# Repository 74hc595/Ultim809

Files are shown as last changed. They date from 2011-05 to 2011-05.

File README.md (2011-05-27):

Ultim809 Homebrew 8-Bit Computer
================================

Matt Sarnoff ([http://msarnoff.org/](http://msarnoff.org))

The Ultim809 is a homebrew 8-bit computer built around the Motorola 6809 processor. It's a full-featured home computer with color graphics, sound, and support for game controllers and PS/2 keyboards.

It won two blue ribbons (Editor's Choice awards) at Bay Area Maker Faire 2011!

Full feature list:

*  Motorola 68B09E processor at 2 MHz
*  512KB static RAM (bank-switched, 48KB available at once) expandable to 4MB
*  8KB EEPROM, self-programmable
*  TMS9918A graphics chip and composite video output (256x192 resolution, 15 colors, 32 sprites)
*  YM2149 sound chip (3 channels, square wave/noise, envelope generator)
*  Two ports for 9-pin Atari joysticks or Sega Genesis gamepads
*  Serial interface (16550 UART) with 6-pin FTDI connector
*  PS/2 keyboard support
*  I2C interface and DS1307 real-time clock with backup battery
*  SD card slot (not working yet...)
*  Expansion slot, supports 4 devices without additional decoding circuitry

I am making the schematics, design files, and source code available to anyone interested in learning about the project, or constructing their own. All material is made available under my (very simple) [msarnoff.org license.](http://www.msarnoff.org/LICENSE)

Schematics and PCB layout file are provided for use with the [open-source gEDA suite.](http://gpleda.org) Be aware that board revision 0 has errors: I have provided instructions on correcting them by cutting traces and adding wires.

Ultim809 currently has no working mass storage, so a PC with a Unix-like operating system (Linux, Mac OS X, etc.) and command-line skills are recommended for working with Ultim809. You'll also want a [5 volt FTDI USB-to-serial cable.](http://www.sparkfun.com/products/9718)

No microcontrollers or programmable logic chips are used, so an expensive programmer is not required. The 8K EEPROM can be programmed with a [simple Arduino circuit.](https://github.com/74hc595/ROMBurner)

The 68B09E is still available from Jameco and other electronics retailers, but you'll probably have to buy the TMS9918A and YM2149 from eBay.

Directory structure
-------------------
`circuit/` contains the schematic, bill of materials, and PCB layout files.

`code/` contains the assembly code for the ROM and application programs, as well as tools for writing your own programs.

`code/user/DEVELOPING.md` contains tips for developing Ultim809 applications. It assumes a familiarity with 6809 assembly language.

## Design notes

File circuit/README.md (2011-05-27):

Ultim809 Schematic and PCB Layout Files
=======================================

`ultim809.sch` is the up-to-date schematic in gEDA format.

`ultim809.pdf` is provided for those who do not have gEDA installed.

`bom.txt` is an up-to-date bill of materials, including sources and part numbers.

Snapshots of the schematic and PCB files for each board revision are included. Be aware that revision 0 has several design errors (steps to correct them are included in `bringup.pdf`) but it is included for completeness.

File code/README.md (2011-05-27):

Ultim809 Code
=============

This directory contains all assembly source code for the Ultim809 ROM and various application programs. Additional scripts to aid development are also included.

All code is written for the open-source ASxxxx cross assembler by Alan R. Baldwin, available online at [http://shop-pdp.kent.edu/ashtml/asxxxx.htm](http://shop-pdp.kent.edu/ashtml/asxxxx.htm). The SRecord suite is also required to create executable files. It's in many package repositories (including Ubuntu and MacPorts) and can also be downloaded from [http://srecord.sourceforge.net/](http://srecord.sourceforge.net/).

Directory structure
-------------------

`rom/` contains the ROM source, and various scripts to generate header files and checksums.

`user/` contains the source of various application programs, and a directory of common include files.

`ser09.py` is a script used to send programs to Ultim809 over a USB-to-serial cable. It can be used to download user programs, as well as update the ROM. See the file for usage details.

`gfx2inc.py` slices an image file into 8x8 or 16x16 tiles and converts them to hexadecimal `.fcb` directives, suitable for including in an assembly program.

`text2inc.py` converts a text file (any file, actually) to hexadecimal `.fcb` directives, suitable for including in an assembly program.

`ym2149.py` includes functions for converting frequencies in hertz to register values for the YM2149 sound chip, and vice versa.

`httpserial.py` is a script that acts as a serial-to-HTTP bridge, allowing Ultim809 to request the contents of URLs over the serial port.

`as6809.vim` is a syntax highlighting file for Vim.

Current features
----------------
Currently, Ultim809 has no mass storage and no interactive monitor. (The prototype did, and I'll be bringing these features over soon.) Programs must be loaded over the serial port using the following procedure:

1.  Make sure a USB-to-serial cable is connected to your PC.
2.  Make sure Ultim809 is on and running (HALT/RUN switch set to RUN).
3.  Press the INTERRUPT button. "Remote ready." should be displayed.
4.  On the PC, run `ser09.py run myprogram.s19`
5.  The status LED should blink yellow and the program should start when the transfer is complete. If not, run `ser09.py run`

The serial device can be changed with the `$SER09_PORT` environment variable. See the script for more details. The ser09 protocol is subject to change in future versions of the ROM.

Code has been written to do the following:

*  write to and read from the serial port
*  display numbers in hex and decimal
*  convert hex and decimal strings to 8- and 16-bit integers
*  generate random numbers with a simple linear feedback shift register
*  interface with the TMS9918A video chip and the YM2149 sound chip
*  read Atari joysticks and Sega 3-button gamepads
*  read the PS/2 keyboard using the 6522A, with a 16 byte scancode buffer
*  convert keyboard scancodes to ASCII characters
*  interface with I2C devices using the 6522
*  get data from the DS1307 real-time clock and set the time
*  download HTTP data from the httpserial.py script running on a PC

The following features of the board are not yet supported, but will be:

*  SPI using the 6522 shift register
*  reading and writing to SD cards
*  FAT16 filesystem operations
*  interactive monitor/command line

Emulation
---------
A somewhat-complete Ultim809 plugin for the MESS emulator is also available from my GitHub. It supports graphics, video, and gamepads, but the keyboard is not emulated.

Writing your own programs
-------------------------
See the `DEVELOPING.md` file in the `code/` directory to learn how to write your own assembly language programs. Note that future revisions of the ROM might require your programs to be reassembled.

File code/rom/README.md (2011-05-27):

Ultim809 ROM
============

A Makefile is included to build the ROM on a Unix-like machine with the ASxxxx assembler.

The following scripts are run by the Makefile:

`map2inc` takes the `rom.map` file as an input and generates a `rom0x.inc` header file, that defines the addresses of all global ROM subroutines. (those whose labels are suffixed with a double colon `::`) This file should be included by all user programs.

`gensums` computes the CRC32 and SHA1 hashes of the ROM binary and outputs the results in `checksum.h`. This file is used by the Ultim809 emulator for MESS.

Tests
-----
Simple test programs are provided in the `tests/` directory. They can be used to test basic system functionality before installing the full ROM.

Modifying the ROM
-----------------
Currently, all ROM routines are called by absolute address. If the ROM is modified, all user programs will have to be reassembled to reference the routines' new addresses, or they will crash. This is done for high performance, but may change in the future to improve portability.

ASlink apparently supports separate assembly, but in a very strange way that makes debugging difficult. The quick solution was to include all subroutine `.asm` files from `main.asm`. This means that a `make clean all` is required after modifying a file other than `main.asm`.

`remote.asm` contains the code to receive programs and ROM upgrades from `ser09`. Currently it only supports programming AT28C64B EEPROMs, 64 bytes at a time.

Uploading the ROM
-----------------
To bootstrap the system, you can use my ROMBurner Arduino sketch to burn the `rom.s19` file to an EEPROM chip with ser09:

`ser09.py load rom.s19`

Additionally, ser09 can be used to program the ROM directly on the board. In this case, power on the system, press the INTERRUPT button, turn the EEPROM PROTECT switch to OFF, and then run the command above. If all is OK, turn the EEPROM PROTECT switch back to ON and press the RESET button.

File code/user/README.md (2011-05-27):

Ultim809 User Programs
======================

These are some of the application programs I have written for Ultim809. Some are incomplete, but they demonstrate all the functionality of the machine.

For information on writing your own programs, see `DEVELOPING.md`.

The ser09 utility can be used to send programs to Ultim809. Connect a 5-volt FTDI USB-to-serial cable, power on the machine, and press the INTERRUPT button. Then, from a terminal on the PC, run

`ser09.py run myprogram.s19`

(`.s19` files are the Motorola equivalent of Intel HEX files, a text representation of the binary executable.) The status LED should blink yellow. If the program does not run after ser09 prints "All OK," you can issue the command

`ser09.py run`

Depending on your system, this might happen often. If that's the case, use this command instead:

`ser09.py load myprogram.s19 && ser09.py run`

Programs
--------

### asteroids
Nearly-complete Asteroids clone. The most complex Ultim809 program.

### date
Get and set the date/time from the DS1307 real time clock.

### kbdtest
Tests the PS/2 keyboard routines.

### life
Conway's Game of Life animation with color and generative music.

### padtest
Gamepad/joystick button test.

### plasma
Old-school rainbow plasma effect.

### vidtest
Basic test of the video chip.

### weather
Downloads and displays weather information using `httpserial.py` running on a host PC.

Include files
-------------
Supplemental routines, not included in the ROM, are provided in the `include/` directory.

### ds1307.asm
Routines to get and set the date and time from the DS1307.

### httpser.asm
Routines to communicate with `httpserial.py`.

### i2c.asm
Bit-banged I2C routines using the 6522A VIA.

### numio.asm
Routines to print numbers in decimal and convert strings to integers.

### random.asm
Simple LFSR-based pseudorandom number generator.

### readline.asm
Routine to read a line of input from the keyboard or serial port.

### ym2149.asm
Routines to interact with the YM2149 sound chip and read the game controllers.

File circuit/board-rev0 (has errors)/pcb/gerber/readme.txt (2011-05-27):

Layers:
u809.frontsilk.gbr    - silkscreen (top), includes board outline
u809.frontmask.gbr    - top solder mask
u809.front.gbr        - top copper
u809.back.gbr         - bottom copper
u809.backmask.gbr     - back solder mask

u809.plated-drill.cnc - Excellon drill file
u809.fab.gbr          - Fabrication drawing (informational only)

All files are positive polarity. Populated areas on solder mask files
indicate areas without solder mask.

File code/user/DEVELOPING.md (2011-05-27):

Developing Applications for Ultim809
====================================

What you'll need
----------------

*  A Unix-like system (Linux, Mac OS X, etc.) You're on your own if you use Windows.
*  A 6809 assembler. I use [ASxxxx](http://shop-pdp.kent.edu/ashtml/asxxxx.htm), and I have included Makefiles for it. It's full-featured, but uses somewhat nonstandard syntax. [asmx](http://xi6.com/projects/asmx/) uses traditional Motorola syntax, but I haven't tried it.
*  The SRecord package, installed through apt-get, MacPorts, or from the [website.](http://srecord.sourceforge.net)
*  I recommend using Vim with the `as6809.vim` syntax highlighting file (in the `code/` directory) and 8 spaces per tab.

6809 assembly language
----------------------
I won't go into the details of 6809 assembly language here. There are very few tutorials available, but the Motorola 6809 Programming Manual is available online [here](http://www.classiccmp.org/dunfield/r/6809prog.pdf) and is a good reference. I have also tried to comment my code as thoroughly as possible so that others might learn from it.

### The basics
There are two 8-bit accumulators, A and B. Together, they make up the 16-bit accumulator D. Supported operations include addition, subtraction, comparison, test, bitwise operations, shifts/rotates, and 8x8 unsigned multiply.

There are two 16-bit index registers, X and Y. They are typically used to hold pointers. All load, store and modify operations can use the addresses stored in X and Y, with optional displacement (by a constant or register value), autoincrement/decrement, and indirection.

There are not one, but _two_ stack pointers, S and U. Both act just like index registers, with the addition of "push" and "pull" instructions. S is the hardware stack pointer, used to store return addresses. You can do whatever you want with U, mostly it's used as a third index register.

The program counter, PC, is 16-bit, and can be used for program-counter-relative addressing when writing position-independent code.

DP is the direct page register, it holds the upper 8 bits of the effective address in direct addressing mode. **On the Ultim809 it should be kept set to 0, see below.**

CC is the condition code register. Condition flags are C (bit 0, carry), V (overflow), Z (zero), N (negative), I (IRQ interrupt inhibit), H (half-carry), F (FIRQ interrupt inhibit) and E (bit 7, entire machine state stacked on interrupt).

Most instructions operate on one register and one memory location (or immediate value). A couple instructions (transfer, exchange) operate on two registers, and some operate directly on memory. The 6809 has plenty of addressing modes, nearly all of which can be used with every instruction. See the programming manual for more information, there are too many to describe here, but they're awesome.

The address space
-----------------
The 6809, like other 8-bit processors, has a 16-bit address bus, and thus a 64K address space. The ROM lives at 0xE000-0xFFFF, and I/O devices are memory mapped in the range 0xC000-0xDFFF. The remaining 48K is RAM.

	0000 +-------------------------+
	     |                         | 0000-007F: system reserved RAM
	     |        User RAM         | 0080-00FF: availble zero-page RAM
	     |     (bank 0, fixed)     | 0100: user program start
	     |                         |
	4000 +-------------------------+
	     |                         |
	     |        User RAM         |
	     |     (bank 1, fixed)     |
	     |                         |
	8000 +-------------------------+
	     |                         |
	     |        User RAM         |
	     |    (selectable bank)    |
	     |                         |
	C000 +-------------------------+
	     |       I/O devices       | C001: bank select register
	     |      (see I/O map)      |
	E000 +-------------------------+
	     |           ROM           |
	     |       (8K EEPROM)       |
	     +-------------------------+

The RAM is divided into 16K banks. Banks 0 and 1 are always present in the lower 32K of the address space. The next 16K ($8000-$BFFF) is a user-selectable bank. The bank can be changed by writing to address $C001. (VIA output register A) A maximum of 256 banks (4 megabytes) are supported. The standard 512K system has 32 banks.

User programs are always loaded at address $0100. They are welcome to place their stack anywhere in user RAM, though I recommended the last address of bank 0 or 1 ($3FFF or $7FFF). **Note that the stack pointer should be initialized to one byte _past_ the last stack byte: i.e. $4000 or $8000.**

Direct page register
--------------------

While the 6502 allows direct addressing only from the zero page, the 6809 allows direct addressing from any of the 256 256-byte pages, controlled by the direct page register DP. For now, **do not mess with DP. Leave it set to 0.** The ROM routines expect DP to be 0, direct addressing is used to save space and cycles. If you're careful, you can mess with DP as long as you set it back to 0 before calling any ROM routines, but **the keyboard interrupt handler expects DP to be 0 as well.** You've been warned.

Interrupts and vectors
----------------------
The 6809 has three hardware interrupts (NMI, IRQ, and FIRQ) and three software interrupts (SWI, SWI2, and SWI3). All six interrupts transfer control to customizable vectors stored in the zero page. Interrupt behavior can be changed by storing interrupt handler addresses to `NMIVEC`, `IRQVEC`, `FIRQVEC`, `SWIVEC`, `SWI2VEC`, and `SWI3VEC`. 

### Hardware interrupts

NMI enters the monitor and enables remote program downloading. It is triggered by pressing the INTERRUPT button.

FIRQ is asserted by the VIA and is used for the keyboard handler. If you wish to use the keyboard and connect another interrupt source to FIRQ, your interrupt handler should call `KBD_HANDLER` to make sure the keyboard data bit is received.

IRQ is used for the TMS9918A VDP's vertical blanking interrupt. When enabled, it is asserted 60 times a second. The VDP's status register must be read to clear the interrupt.

### Software interrupts

The software interrupts are not currently used, but they will be in a future revision of the ROM.

SWI is intended to be used as a breakpoint instruction. It will trap into the monitor, keeping the program running.

SWI2 should be used as a "quit program" instruction. It will return control to the shell.

SWI3 has no planned use. Go nuts.

### Character input/output

The `OUTCH` and `INCH` vectors are used for character input and output routines. They act similar to standard input and output and may be configured to use the screen/keyboard or the serial port.

`OUTCH` is used by all the string/numeric output functions in the ROM.

Calling `UART_IO` will set up `OUTCH` and `INCH` to use the serial port.

The subroutine pointed to by `OUTCH` should take the character to be output in the B register and destroy no other registers.

The subroutine pointed to by `INCH` should return a character in the B register and destroy no other registers. It should block until a character has been received.

Program structure
-----------------

The typical control flow of a graphical application is fairly simple:

*  Set the stack pointer
*  Clear VRAM, turn the display off, and send pattern/color data to the VDP
*  Initialize program variables and data structures
*  Enable the keyboard and vblank interrupts
*  Turn the display on
*  Begin the logic update loop

The logic loop should be used for updating game/program logic. A `sync` instruction at the end of the loop (just before the jump back to the beginning) ensures it is called at a rate of 60 Hz.

The vblank interrupt handler should be used for all writes to video RAM, since there is no need to wait for an access window.

### Multiple assembler files

Since I haven't quite figured out separate assembly/linking with AS6809, the easiest way to assemble multiple files is to `.include` them at the end of the main `.asm` file. If one of the included files is modified, you'll have to rebuild with `make clean all`.

### Text-based programs

If you're making a "command-line" program that uses the screen in 40x24 text mode and the keyboard, you can set everything up with a call to `TEXT_CONSOLE` at the start of the program. All character I/O can then be done with `OUTCH` and `INCH`, and there is no need to directly manipulate video memory. A vblank handler is not installed.

### Program layout

See `stub.asm` and `Makefile_stub` for a new program template.

I/O devices
-----------

The I/O devices are accessed through memory addresses in the range $C000-$DFFF. Here is the full I/O device map:

	$C000-$C00F - 6522A Versatile Interface Adapter
	$C001       - bank select register (VIA port A output register)
	$C400-$C407 - 16550 UART (serial port)
	$C404       - controls status LED color (UART modem control register)
	$C800       - SPI input shift register
	$CC00-$CC01 - TMS9918A Video Display Processor
	$CC02-$CC03 - YM2149 Programmable Sound Generator
	$CC04       - read to select lower 16K of VRAM
	$CC06       - read to clear the controller SELECT lines
	$CC0C       - read to select upper 16K of VRAM
	$CC0E       - read to set the controller SELECT lines
	$D000-$D3FF - external device #1
	$D400-$D7FF - external device #2
	$D800-$DBFF - external device #3
	$DC00-$DFFF - external device #4
	
### 6522A VIA

[Datasheet](http://www.westerndesigncenter.com/wdc/documentation/w65c22.pdf)

The VIA is used mainly by the ROM routines, in most cases you don't need to touch it directly. Port A controls the upper 8 address lines, so writing to the port A output register (address $C001) changes the selected memory bank.

You should not change the Data Direction Registers. Port A should be set to all outputs and Port B should be set to all inputs.

### 16550 UART

[Datasheet](http://www.national.com/ds/PC/PC16550D.pdf)

The UART is initialized on powerup to operate at 38400 baud, 8 data bits, no parity, 1 stop bit. The `UART_INIT` subroutine can be used to reinitialize the UART with a different baud rate. You should pass the appropriate `B*` baud rate constant in the X register.

Calling `UART_IO` sets up the character I/O routines `OUTCH` and `INCH` to use the serial port.

The status LED is controlled by the two general-purpose outputs. `UART_SETLED` is a convenience method for changing the status LED color.

The FIFO, DMA, and interrupt functions are not used. The interrupt line is not connected.

### TMS9918A VDP

[Datasheet](http://www.cs.columbia.edu/~sedwards/papers/TMS9918.pdf)

The VDP has two addresses: the register write address, and the VRAM write address.

`tms9918.asm` in the `rom/` directory contains plenty of subroutines for interacting with the VDP and VRAM. Calling `VDP_CLEAR` at the start of your program is always a good idea to prevent graphics corruption.

`VDP_SET_REGS` sets all 8 control registers from an 8-byte block of memory pointed to by X.

`VDP_LOADPATS` makes it easy to copy 8-byte chunks of data (color table entries, pattern table entries) to VRAM.

`VDP_INITTEXT` automatically places the VDP in 40x24 text mode and copies the text character set to VRAM.

If possible, don't write to VRAM unless the display is off, or you're in the vblank handler. Read the datasheet: when the display is active, the VDP can require up to 8 microseconds before it's ready to write a byte to memory.

It's possible to transfer about 1K of data in the vertical blanking interval (which is 4300 microseconds long). It's enough for an entire name table update if you unroll your loop a whole lot.

The Ultim809 actually has 32K of VRAM, though the VDP can only access 16K at once. Doing an `lda` from `VBANK_LOWER` or `VBANK_UPPER` selects a VRAM bank. Its effectiveness as a double buffer is limited, since you can't write into one bank and have another displayed onscreen.

### YM2149 PSG

[Datasheet](http://www.ym2149.com/ym2149.pdf)

The YM2149 (also known as the AY-3-8910) runs off the 2MHz system clock. It has three channels, each of which can play a square wave, noise, or both. Each channel can either use a 4-bit volume value, or the waveform from the envelope generator.

Helpful subroutines, along with formulas to convert frequencies in Hz to register values, are in the `include/ym2149.asm` file.

The YM2149 is also used to read the controller ports. The two I/O ports should always be configured as inputs.

6809 assembler tips/idioms
--------------------------

This section won't serve as a full 6809 assembler tutorial, it's meant to be a collection of knowledge snippets I accumulated over the course of the project.

### Some index registers are faster than others
`ldy`/`sty` and `lds`/`sts` are one cycle _slower_ than `ldx`/`stx` and `ldu`/`stu`. It's recommended to use U as an index register before Y. `cmpx` is one cycle faster than all the other 16-bit register compares.

### 16-bit shifts and negation

Shift D left one bit:

	lslb
	rola
	
Shift D right one bit, unsigned:

	lsra
	rorb

Shift D right one bit, maintaining sign:

	asra
	rorb
	
Negate D:

	coma
	comb
	addd #1

### Reserve stack space during subroutines
If you run out of registers in a subroutine and need temporary space during a subroutine, use `leas` with a negative constant offset:

	leas -4,s	;reserve 4 bytes of stack space
	;do stuff
	leas 4,s	;restore stack space
	rts
		
### Know your flags

`inc` and `dec` affect the Negative, Zero, and Overflow flags. You can use a branch instruction directly after them.

All `ld` instructions set the Zero and Negative flags. You can use a branch instruction directly after them.

`leax` and `leay` set the Zero flag if the result is zero, `leas` and `leau` do not affect the Zero flag.

`clr` always sets the Carry flag. Use `ld #0` to zero a register without affecting the Carry flag.

### Quick 3-way logic tests
Branch instructions preserve the condition codes, so, for example, the following snippet can test if a number is zero, negative, or positive:

	ldb #somenumber
	beq number_is_zero
	bmi number_is_negative
	;number is positive
	
### Use `lea` instead of `tfr` with index registers
`leax ,y` is two cycles faster than `tfr y,x`.

### Use `lea` for 16-bit increments/decrements
`leax -1,x` will decrement X. `leax` and `leay` also set the Zero flag, so if you need a 16-bit loop counter, use X and Y instead of D.

### Tail calls
If the last instruction of a subroutine is a call to another subroutine, use `bra` or `jmp` instead of `bsr`/`jsr`. Also consider grouping subroutines together so one can "fall through" to another.

### Return from subroutine and restore registers with one instruction
`rts` is equivalent to `puls pc`. PC is always the last register pulled in a sequence, so if you had to push register values on the stack at the start of a subroutine, they can be restored along with the program counter. So instead of

	pshs d,x,y
	;do stuff here
	puls d,x,y
	rts

just do

	pshs d,x,y
	;do stuff here
	puls d,x,y,pc

This saves one byte and three cycles.

### For loops

If you have a free accumulator register, use it as the loop counter:

		lda  #5
	loop:
		;do stuff
		deca
		bne  loop
		
This works for up to 256 iterations: if A is 0, the `deca` will cause a wraparound and the loop will execute 256 times.

If you need both A and B during the loop, put the loop counter on the stack:

		lda  #5
		pshs a
	loop:
		;do stuff
		dec  ,s
		bne  loop
	done:
		leas 1,s
		
If you need a 16-bit loop counter, use X or Y, since `leax` and `leay` affect the Zero flag.

### Zero-terminated string/list processing
If you need to iterate through a list of characters/16-bit integers and stop when a zero is found, use autoincrementing address mode. For example, a routine to copy a null-terminated string pointed to by X to memory pointed to by Y:

	loop:
		ldb  ,x+
		beq  done
		stb  ,y+
		bra  loop

### Use constant offset indexing for data structures
Let's say X points to an array of 4-byte ordered pairs: a 2-byte x coordinate and a 2-byte y coordinate. Use `.equ` statements to give field names to structure offsets:

	xcoord		.equ 0
	ycoord		.equ 2
	POINT_SIZE	.equ 4
	
Now let's say you had a point in U and wanted to add its x and y coordinates to all points in the array pointed to by X. You could do something like this:

	loop:
		ldd  xcoord,x
		addd xcoord,u
		std  xcoord,x
		ldd  ycoord,x
		addd ycoord,u
		std  ycoord,x
		leax POINT_SIZE,x
		cmpx #POINTS_END
		bne  loop
		
### Table lookups
Indexed addressing with register offset is great for performing table lookups. For example, to get the byte in a table specified by the value in A:

	ldu  #TABLE
	ldb  a,u
	
A can be multiplied by 2 to perform a lookup in a table of 2-byte values:
	
	ldu  #TABLE
	lsla
	ldd  a,u
	
Note that register offsets are signed, so the first example only works with tables of 128 entries or less, and the second only works with tables of 64 entries or less.

There are a couple ways to perform a lookup in a table greater than 128 bytes and less than 256 bytes. One is to put the table pointer in X, the table offset in B, and use `abx`, which performs an unsigned addition:

	ldx  #TABLE
	abx
	ldb  b,x
	
The other is to shift B one bit left into A and use a 16-bit offset:

	ldu  #TABLE
	clra
	lslb
	rola
	ldb  d,u
	
However, this method is more expensive.

If your table is exactly 256 bytes, you can use an 8-bit register offset if you arrange your table in a clever way to take advantage of two's complement arithmetic. The first byte in the table will correspond to an offset of 128 (%10000000 or -128 in two's complement) The 129th byte will correspond to an offset of 0, so you should set your label to point to this byte in the table instead of the first. An example, using the identity table:

		.fcb 128,129,130,131
		;...
		;.fcb 252,253,254,255
	TABLE:
		.fcb 0,1,2,3
		;...
		.fcb 124,125,126,127
		
### Swap the bytes in a 16-bit number

	ldd  NUMBER
	exg  a,b
	std  NUMBER

Even better, if the source of the 16-bit numbers is a table, store them byte-swapped if possible!

### Set a YM2149 register with one instruction
When setting a register in the YM2149, first you write the register number to `PSG_LATCH_ADDR`, then the register value to `PSG_WRITE_ADDR`. However, since these addresses are right next to each other, both can be set with a 16-bit write:

	lda  #REGISTER_NUMBER
	ldb  #REGISTER_VALUE
	std  PSG
	
Or, combine both values with bitwise operations:

	ldd  #(REGISTER_NUMBER<<8)|REGISTER_VALUE
	std  PSG
	
### Set the VDP VRAM address
The TMS9918A has a strange memory addressing scheme: to write to or read from VRAM, the address must first be set, and it autoincrements with each read/write. When setting the VRAM address, two bytes must be written to the VDP register: the 14-bit VRAM address, with the secondmost-significant-bit set to 1, little-endian. The VDP can only receive a byte every 2 microseconds (4 cycles), so a 16-bit store instruction can't be used. Instead, write both bytes separately:

	ldd  #NEW_VRAM_ADDRESS
	ora  #0x40
	stb  VDP_REG
	sta  VDP_REG
	
The `VRAM` define is included to make things easier to understand:

	ldd	 #VRAM|NEW_VRAM_ADDRESS
	stb  VDP_REG
	sta  VDP_REG
	
### Sometimes it's better to not restore register values
Let's say you're writing a subroutine to process a chunk of data, like a zero-terminated string. You have a subroutine that takes a pointer to a zero-terminated string in X:

	SUBROUTINE:
		pshs x
	loop:
		ldb  ,x+
		beq  done
		;do stuff
		bra  loop
	done:
		puls x,pc
		
X is advanced inside the subroutine, but restored when it returns. Now what happens if you have to call this subroutine multiple times in a row?

	ldx  #string1
	jsr  SUBROUTINE
	ldx  #string2
	jsr  SUBROUTINE
	ldx  #string3
	jsr  SUBROUTINE
	;...
	string1: .asciz "This is string one"
	string2: .asciz "This is string two"
	string3: .asciz "This is string three"
	
If we modify `SUBROUTINE` to **not** restore X, it will point to the start of the next string on return, so we don't have to re-set X, and can just do this:

	ldx  #string1
	jsr  SUBROUTINE
	jsr  SUBROUTINE
	jsr  SUBROUTINE
	
If you're calling the same subroutine a bunch of times, it can be _faster_ to store the subroutine address in an index register:

	ldx  #string1
	ldu  #SUBROUTINE
	jsr  ,u
	jsr  ,u
	jsr  ,u

### Disable and enable interrupts
The 6809 doesn't have explicit enable/disable interrupt instructions. Instead, use the `orcc` and `andcc` instructions to directly modify the bits in the CC register:

	orcc  #0b01010000 ;disable interrupts (set bits F and I)
	andcc #0b10101111 ;enable interrupts (clear bits F and I)

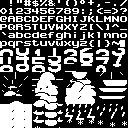
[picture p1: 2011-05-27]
code/user/weather/graphics.png

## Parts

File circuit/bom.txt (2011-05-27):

Refdes		Part			Value/part #	Qty	
B1		BATTERY_HOLDER		Jameco 355434	1	
C1,C3,C5,C6	POL_CAPACITOR		10uF		4	
C7		POL_CAPACITOR		1uF		1	
C8		CAPACITOR		27pF		1	
C9		CAPACITOR		47pF		1	
C10,C11,C14	CAPACITOR		33pF		3	
C12		POL_CAPACITOR		22uF		1	
C13,C16-C42	CAPACITOR		0.1uF		30	
C15		POL_CAPACITOR		220uF		1	
D1		1N4001					1	
D2,D3,D4	LED			GREEN, T1	3	
D5		LED			TRICOLOR, T1	1	
D6,D7		1N4148					2	
J1		PWRJACK			Jameco 101186	1	
J2		CONNECTOR_6				1	
J3		minidin-6		Jameco 119475	1	
J4		CONNECTOR_4				1	
J5		RCA, WHITE		Jameco 220581	1	
J6		RCA, YELLOW		Jameco 220564	1	
J7		CONNECTOR_11				1	
J8		SD_SOCKET				1	
J10,J9		DB9			Jameco 104943	2	
J11		HEADER34				1	
J12		HEADER40				1	
L1		BEAD					1	
Q1		2N3904 (center base)			1	
R1		RESISTOR		330		1	
R3-R8		RESISTOR		1k		6	
R9		RESISTOR		4.7k		1	
R10		RESISTOR		1M		1	
R11,R2		RESISTOR		1.5k		2	
R12,R14,R17	RESISTOR		1.8k		3	
R13,R15,R18	RESISTOR		3.3k		3	
R16		RESISTOR		10k		1	
R19		RESISTOR		470		1	
R20,R21		RESISTOR		75		2	
RN1,RN3		RESISTORPACK_6		10k		2	
RN2		RESISTORPACK_6		1k		1	
S1		SPDT ON-ON		Jameco 71597	1	
S4,S5		SPDT ON-ON		Jameco 75969	2	
S2,S3		PUSHBUTTON_NO				2	
U1		7805					1	
U2		LD1117V33				1	
U3		74HC73					1	
U4		MC68B09E				1	
U5		74HC00					1	
U6		74HC14					1	
U8		628512					1	
U9		28C64/AT28C64B				1	
U10		74HC138					1	
U11		6522A/W65C22S				1	
U12		74HC157					1	
U13		74HC08					1	
U14		74HC595					1	
U15		DS1307					1	
U16		16C550					1	
U17,U7		74HC139					2	
U18		74HC02					1	
U19		74HC74					1	
U20		YM2149			eBay		1	
U21		TMS9918A		eBay		1	
U22		74HC04					1	
U23,U24,U25	74HC574					3	
U26		62256					1	
U27		74HC245					1	
U28,U29		74HC541					2	
X1		OSC			8MHz		1	
X2		CRYSTAL			1.8432MHz	1	
X3		CRYSTAL			10.738635MHz	1	
X4		CRYSTAL			32.768kHz	1	
                                                                
		8-PIN DIP SOCKET			1	
		14-PIN DIP SOCKET			10	
		16-PIN DIP SOCKET			3	
		20-PIN DIP SOCKET			6	
		28-PIN DIP SOCKET			2	
		32-PIN DIP SOCKET			1	
		40-PIN DIP SOCKET			5

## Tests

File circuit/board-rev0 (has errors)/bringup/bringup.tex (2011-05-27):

\documentclass[letterpaper,11pt]{article}
\usepackage{fullpage}
\usepackage{graphicx}
\usepackage{underscore}
\usepackage{siunitx}

\newcommand{\net}[1]{\textsf{#1}}
\newcommand{\Net}[1]{\ensuremath{\overline{\textsf{#1}}}}
\newcommand{\Wbar}{\ensuremath{\overline{\textsf{W}}}}
\newcommand{\Vcc}{\net{Vcc}}
\newcommand{\GND}{\net{GND}}
\newcommand{\Pin}[1]{\textbf{Pin #1}}
\newcommand{\pin}[1]{\textbf{pin #1}}
\newcommand{\pins}[1]{\textbf{pins #1}}
\newcommand{\npin}[2]{\pin{#1} (\net{#2})}
\newcommand{\Npin}[2]{\pin{#1} (\Net{#2})}
\newcommand{\rpin}[2]{\refdes{#1} \pin{#2}}
\newcommand{\rpins}[2]{\refdes{#1} \pins{#2}}
\newcommand{\rnpin}[3]{\refdes{#1} \pin{#2} (\net{#3})}
\newcommand{\rNpin}[3]{\refdes{#1} \pin{#2} (\Net{#3})}
\newcommand{\rnpins}[3]{\refdes{#1} \pins{#2} (\net{#3})}
\newcommand{\refdes}[1]{\textbf{#1}}
\newcommand{\kohm}[1]{\SI{#1}{\kilo\ohm}}
\newcommand{\Mohm}[1]{\SI{#1}{\mega\ohm}}
\newcommand{\pF}[1]{\SI{#1}{\pico\farad}}
\newcommand{\uF}[1]{\SI{#1}{\micro\farad}}
\newcommand{\V}[1]{\SI{#1}{\volt}}
\newcommand{\MHz}[1]{\SI{#1}{\mega\hertz}}
\title{Ultim809 Rev 0 Board Bringup Procedure}
\author{Matt Sarnoff}
\date{\today}

\begin{document}
\maketitle
\section{Board Errors}
\subsection{\refdes{U4} \net{TSC}}
\Pin{39} of \refdes{U4} (\net{TSC}) is incorrectly connected to \Vcc. It should be connected to \GND. Cut the trace on the top side of the board as follows:

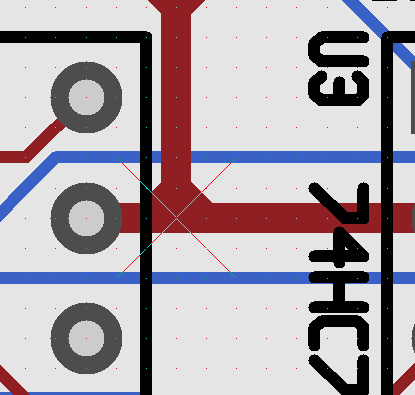
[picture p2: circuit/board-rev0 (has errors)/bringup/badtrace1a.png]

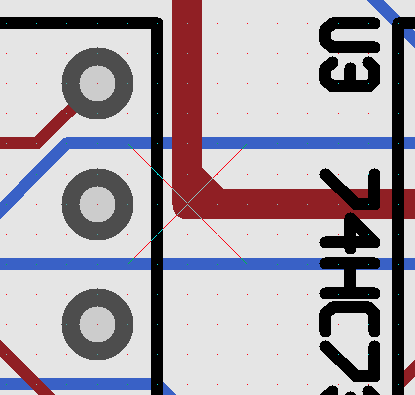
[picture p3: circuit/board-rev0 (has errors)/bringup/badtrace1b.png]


On the bottom of the board, solder a piece of enameled magnet wire or wire-wrap wire from \pin{39} to \pin{1}.

\subsection{\refdes{U16} \net{TX} and \net{RX} swapped}
\rnpin{U16}{10}{RX} is mistakenly connected to \rnpin{J2}{5}{RXD}, and \rnpin{U16}{11}{TX} is mistakenly connected to \rnpin{J2}{4}{TXD}. These two need to be swapped. Since it is difficult to fix this on the board, you will have to fashion an adapter on a piece of perfboard.

\subsection{\Net{CSW} and \Net{CSR} swapped}
\rNpin{U21}{14}{CSW} is mistakenly connected to \rpin{U17}{11} and \rNpin{U21}{15}{CSR} is mistakenly connected to \rpin{U17}{10}. The two should be swapped. Cut traces on the back of the board at \rpin{U17}{10-11}. Add a wire from \rpin{U17}{11} to \rpin{U21}{15} and a wire from \rpin{U17}{10} to \rpin{U21}{14}.

\subsection{VRAM bus incorrect}
Cut the traces on the back of the board at \rpin{U23}{12} and \rpin{U26}{26}. Add a wire from \rpin{U23}{19} to \rpin{U26}{4} and a wire from \rpin{U24}{19} to \rpin{U26}{26}.

\section{Assembly and testing}

\subsection{Sockets}
\begin{itemize}
\item Install all IC sockets.
\end{itemize}

\subsection{Power}
\begin{itemize}
\item Install \refdes{D2} (power LED), \refdes{R3} (\kohm{1}), \refdes{D1} (1N4001), \refdes{C2} and \refdes{C4} (\uF{0.1}), \refdes{C1} and \refdes{C3} (\uF{10} electrolytic, rated for \V{50}), \refdes{U1} (7805), \refdes{J1}, and \refdes{S1}.
\item Ensure \refdes{S1} is in the down (disconnected) position.
\item Connect \V{9} DC power to \refdes{J1}. The center pin is positive and the outer ring is ground.
\item Turn on \refdes{S1}. \refdes{D2} should light.
\item Measure \Vcc\ (for example, at \refdes{U14} \pin{16}) and ensure it is roughly \V{5}.
\end{itemize}

\subsection{Clock signals}
\begin{itemize}
\item Install \refdes{X1} (\MHz{8}), \refdes{U3} (74HC73), and decoupling capacitor \refdes{C16}.
\item Turn on power.
\item Using a frequency counter, measure the clock signals. \rpin{U3}{1} should read \MHz{8}. \rnpin{U4}{34}{E} and \rnpin{U4}{35}{Q} should read \MHz{2}.
\item Using a two-channel oscilloscope or logic analyzer, observe the \net{E} (\rpin{U4}{34}) and \net{Q} (\rpin{U4}{35}) waveforms.

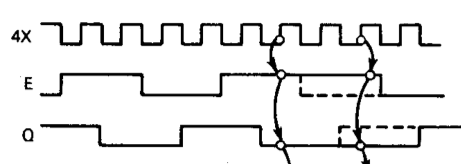
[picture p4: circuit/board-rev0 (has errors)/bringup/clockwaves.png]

\end{itemize}

\subsection{Processor integrity}
\begin{itemize}
\item Install \refdes{RN1} (\kohm{10}), \refdes{C6} (\uF{10}), \refdes{D3} and \refdes{D4}, \refdes{R4} and \refdes{R5} (\kohm{1}), \refdes{S5}, \refdes{S2}, and \refdes{S3}.
\item Flip \refdes{S5} up to HALT.
\item Turn on power.
\item Ensure \rNpin{U4}{40}{HALT} is \V{0}.
\item Ensure \Npin{U4}{37}{RESET}, \Npin{2}{NMI}, \Npin{3}{IRQ}, and \Npin{4}{FIRQ} are \V{5}.
\item Flip \refdes{S5} down to RUN and ensure \pin{40} is \V{5}.
\item Ensure \pin{37} is \V{0} when \refdes{S2} is depressed and \pin{2} is \V{0} when \refdes{S3} is depressed.
\item Turn off power, install \refdes{U4} (68B09E) and decoupling capacitor \refdes{C17}.
\item Flip \refdes{S5} up to HALT and turn on power.
\item Ensure \refdes{D3} and \refdes{D4} are both lit. This indicates the processor is in good condition.
\end{itemize}

\subsection{ROM, program execution, and address decoding}
\begin{itemize}
\item Burn \texttt{romtest1.s19} to an 8K$\times$8 EEPROM, using the Arduino ROMBurner and the \texttt{ser09} utility.
\item Install the EEPROM in \refdes{U9}, and install \refdes{U5} (74HC00), \refdes{U7} (74HC139), \refdes{RN3} (\kohm{10}), \refdes{S4}, and associated decoupling capacitors.
\item Flip \refdes{S4} to the left (EEPROM WRITE PROTECT ON) and ensure \rNpin{U9}{27}{WE} is connected to \rpin{RN3}{6}. (Resistance between \pin{27} and \Vcc\ is \kohm{10}.)
\item Flip \refdes{S4} to the right (EEPROM WRITE PROTECT OFF) and ensure \pin{27} is connected to \rNpin{U8}{29}{WR}.
\item Flip \refdes{S4} to the left and flip \refdes{S5} to HALT.
\item Turn on power. \refdes{D3} and \refdes{D4} should light.
\item Flip \refdes{S5} to RUN. \refdes{D3} and \refdes{D4} should turn off. The program should now be running. After about one second, \refdes{D3} should light (SYNC acknowledge), indicating the test program is finished. Pressing \refdes{S2} or \refdes{S3} will restart the program: the light will go out, and should come on about a second later.
\item Turn off power.
\item With a logic analyzer, attach probes to \rnpins{U4}{8-23}{A0-A15}, \rnpin{U4}{34}{E}, \rnpin{U4}{32}{R/\Wbar}, \rNpin{U5}{6}{RAMSEL}, \rNpin{U7}{4}{IOSEL}, \rNpin{U7}{5}{ROMSEL}, \rNpin{U7}{9}{RD}, and \rNpin{U7}{10}{WR}. The positive edge of \net{E} should be used as the clock signal.
\item Set \refdes{S5} to HALT, run the logic analyzer, and set \refdes{S5} to RUN. Repeat multiple times to verify the following truth table:

\begin{minipage}[t]{0.3\textwidth}
\begin{tabular}[t]{|c|c|c|c|}
\hline
\net{E} & \net{R/\Wbar} & \Net{RD} & \Net{WR} \\
\hline\hline
0 & x & 1 & 1 \\
1 & 1 & 0 & 1 \\
1 & 0 & 1 & 0 \\
\hline
\end{tabular}
\end{minipage}
\begin{minipage}[t]{0.5\textwidth}
\begin{tabular}[t]{|c|c|c|c|}
\hline
\net{A0-A15} & \Net{RAMSEL} & \Net{IOSEL} & \Net{ROMSEL} \\
\hline\hline
\$0xxx & 0 & 1 & 1 \\
\$1xxx & 0 & 1 & 1 \\
\$2xxx & 0 & 1 & 1 \\
\$3xxx & 0 & 1 & 1 \\
\$4xxx & 0 & 1 & 1 \\
\$5xxx & 0 & 1 & 1 \\
\$6xxx & 0 & 1 & 1 \\
\$7xxx & 0 & 1 & 1 \\
\$8xxx & 0 & 1 & 1 \\
\$9xxx & 0 & 1 & 1 \\
\$Axxx & 0 & 1 & 1 \\
\$Bxxx & 0 & 1 & 1 \\
\hline
\$Cxxx & 1 & 0 & 1 \\
\$Dxxx & 1 & 0 & 1 \\
\hline
\$Exxx & 1 & 1 & 0 \\
\$Fxxx & 1 & 1 & 0 \\
\hline
\end{tabular}
\end{minipage}

The test program attempts to read and write to successive addresses, so the address decoding may be observed.
\end{itemize}

\subsection{I/O decoding}
\begin{itemize}
\item Install \refdes{U6} (74HC14), \refdes{U10} (74HC138), and associated decoupling capacitors.
\item Attach logic analyzer probes to \rnpins{U4}{8-23}{A0-A15}, \rNpin{U10}{15}{VIASEL}, \rNpin{U10}{14}{UARTSEL}, \rNpin{U10}{13}{SRSEL}, \rNpin{U10}{12}{AVSEL}, \rNpin{U10}{11}{EXT1SEL}, \rNpin{U10}{10}{EXT2SEL}, \rNpin{U10}{9}{EXT3SEL}, \rNpin{U10}{7}{EXT4SEL}, and \rNpin{U5}{8}{EXTIOSEL}. The positive edge of \net{E} should be used as the clock signal.
\item Run \texttt{romtest1.s19} again and verify the following truth table: 

\begin{tabular}[t]{|c|c|c|c|c|c|c|c|c|c|}
\hline
\net{A0-A15} & \Net{VIA} & \Net{UART} & \Net{SR} & \Net{AV} & \Net{EXT1} & \Net{EXT2} & \Net{EXT3} & \Net{EXT4} & \Net{EXTIO} \\
\hline\hline
\$Bxxx & 1 & 1 & 1 & 1 & 1 & 1 & 1 & 1 & 1 \\
\$C000-\$C3FF & 0 & 1 & 1 & 1 & 1 & 1 & 1 & 1 & 1 \\
\$C400-\$C7FF & 1 & 0 & 1 & 1 & 1 & 1 & 1 & 1 & 1 \\
\$C800-\$CBFF & 1 & 1 & 0 & 1 & 1 & 1 & 1 & 1 & 1 \\
\$CC00-\$CFFF & 1 & 1 & 1 & 0 & 1 & 1 & 1 & 1 & 1 \\
\$D000-\$D3FF & 1 & 1 & 1 & 1 & 0 & 1 & 1 & 1 & 0 \\
\$D400-\$D7FF & 1 & 1 & 1 & 1 & 1 & 0 & 1 & 1 & 0 \\
\$D800-\$DBFF & 1 & 1 & 1 & 1 & 1 & 1 & 0 & 1 & 0 \\
\$DC00-\$DFFF & 1 & 1 & 1 & 1 & 1 & 1 & 1 & 0 & 0 \\
\$Exxx & 1 & 1 & 1 & 1 & 1 & 1 & 1 & 1 & 1 \\
\hline
\end{tabular}
\end{itemize}

\subsection{UART}
\begin{itemize}
\item Install \refdes{U16} (16C550), decoupling capacitor \refdes{C29}, \refdes{R10} (\Mohm{1}), \refdes{R11} (\kohm{1.5}), \refdes{C8} (\pF{27}), \refdes{C9} (\pF{47}), \refdes{X2} (\MHz{1.8432}), \refdes{J2}, \refdes{R1} (\SI{330}{\ohm}), \refdes{R2} (\kohm{1.5}), and \refdes{D5}. Orient \refdes{D5} so the shortest lead (the green anode) is on the left and is inserted into the square hole.
\item Burn \texttt{romtest2.s19} onto the EEPROM.
\item Connect a \V{5} FTDI USB-to-serial cable to \refdes{J2}, with the black wire on the right. Connect the other end to a PC. Start a terminal program listening at 38400 baud, 8 data bits, no parity, 1 stop bit.
\item Turn on the system and run the program.
\item The status LED \refdes{D5} should turn off and the system should print the following:
\begin{verbatim}
Hello World!
Type r, y, g, or o to change LED color
\end{verbatim}
Typing one of the four letters from the terminal changes the LED color (red, yellow, green, off) and prints a message. (``\texttt{Red.}'' or ``\texttt{Yellow.}'' or ``\texttt{Green.}'' or ``\texttt{Off.}'')
\item Additionally, use a frequency counter to check the UART's clock rate at \rpin{U16}{9}. It should be $16\times$ the baud rate: in this case, approximately \SI{614400}{\hertz}.
\end{itemize}

\subsection{RAM and bank switching}
\begin{itemize}
\item Install diode \refdes{D7} (1N4148).
\item Test \refdes{D7} using a multimeter in diode mode. Place the positive lead on \rNpin{U4}{4}{FIRQ} and place the negative lead on \rNpin{U11}{21}{IRQ}. (\refdes{U11} should not be installed yet.) The meter should read a small positive voltage. Reverse the leads and the meter should indicate an open circuit.
\item Install \refdes{U8} (512K SRAM), \refdes{U11} (W65C22S), \refdes{U12} (74HC157), \refdes{U13} (74HC08), and associated decoupling capacitors.
\item Burn \texttt{romtest3.s19} onto the EEPROM.
\item Connect the serial cable and start the terminal as in the previous step.
\item Run the program. It tries to determine the size of the RAM by cycling through the 16K pages and counting them until it detects wraparound. It should print
\begin{verbatim}
0512KB RAM available.
\end{verbatim}
on the console.
\end{itemize}

\subsection{Audio/video I/O decoding}
\begin{itemize}
\item Install \refdes{U17} (74HC139), \refdes{U18} (74HC02), \refdes{U19} (74HC74), and associated decoupling capacitors.
\item Burn \texttt{romtest4.s19} onto the EEPROM.
\item Attach logic analyzer probes to \rNpin{U17}{1}{AVSEL}, \rnpin{U17}{2-3}{A1-A2}, \rNpin{U17}{4}{VDPSEL}, \rNpin{U17}{5}{PSGSEL}, \rNpin{U17}{6}{FF1SEL}, \rNpin{U17}{7}{FF2SEL}, \rNpin{U17}{13}{RD}, \rNpin{U17}{14}{WR}, \rNpin{U17}{10}{CSR}, \rNpin{U17}{11}{CSW}, \rnpin{U18}{3}{A0}, \rnpin{U18}{1}{BC1}, \rnpin{U18}{4}{BDIR}, \rnpin{U18}{13}{FF1CP}, \rnpin{U18}{10}{FF2CP}, \rnpin{U19}{3}{A3}, \rnpin{U19}{5}{VBANK}, and \rnpin{U19}{9}{PADSELECT}. The positive edge of \net{E} should be used as the clock signal.
\item Run the program and verify the following truth tables:

\begin{tabular}{|c|c|c|c|c|c|c|c|c|c|}
\hline
\Net{AVSEL} & \net{A0-A2} & \Net{RD} & \Net{WR} & \Net{VDPSEL} & \Net{PSGSEL} & \Net{FF1SEL} & \Net{FF2SEL} & \Net{CSR} & \Net{CSW} \\
\hline
1 & \%xxx & x & x &   1 & 1 & 1 & 1 &   1 & 1 \\
0 & \%00x & 1 & 0 &   0 & 1 & 1 & 1 &   1 & 0 \\
0 & \%00x & 0 & 1 &   0 & 1 & 1 & 1 &   0 & 1 \\
0 & \%01x & x & x &   1 & 0 & 1 & 1 &   1 & 1 \\
0 & \%10x & x & x &   1 & 1 & 0 & 1 &   1 & 1 \\
0 & \%11x & x & x &   1 & 1 & 1 & 0 &   1 & 1 \\
\hline
\end{tabular}

\begin{tabular}{|c|c|c|c|c|c|c|}
\hline
\Net{AVSEL} & \Net{PSGSEL} & \net{A0-A2} & \Net{RD} & \Net{WR} & \net{BC1} & \net{BDIR} \\
\hline
1 & 1 & \%xxx & x & x & 0 & 0 \\
0 & 0 & \%010 & x & 0 & 1 & 1 \\
0 & 0 & \%010 & x & 1 & 1 & 0 \\
0 & 0 & \%011 & x & 0 & 0 & 1 \\
0 & 0 & \%011 & x & 1 & 0 & 0 \\
\hline
\end{tabular}

\begin{tabular}{|c|c|c|c|c|c|c|c|c|}
\hline
\Net{AVSEL} & \Net{FF1SEL} & \Net{FF2SEL} & \Net{RD} & \net{A3} & \net{FF1CP} & \net{FF2CP} & \net{VBANK} & \net{PADSELECT} \\
\hline
1 & 1 & 1 &   x & x &  0 & 0 &  no change & no change \\
0 & 0 & 1 &   1 & x &  0 & 0 &  no change & no change \\
0 & 0 & 1 &   0 & 0 &  1 & 0 &  0 & no change \\
0 & 0 & 1 &   0 & 1 &  1 & 0 &  1 & no change \\
0 & 1 & 0 &   0 & 0 &  0 & 1 &  no change & 0 \\
0 & 1 & 0 &   0 & 1 &  0 & 1 &  no change & 1 \\
\hline
\end{tabular}
\end{itemize}

\subsection{Audio/gamepads}
\begin{itemize}
\item Install \refdes{U20} (YM2149), \refdes{R6}, \refdes{R7}, and \refdes{R8} (\kohm{1}), \refdes{R9} (\kohm{4.7}), \refdes{C7} (\uF{1}), \refdes{J9}, and \refdes{J10}. Also install decoupling capacitors.
\end{itemize}

\subsection{Video}
\begin{itemize}
\item Install \refdes{U21} (TMS9918A), \refdes{U22} (74HC04), \refdes{U23}, \refdes{U24}, and \refdes{U25} (74HC574), \refdes{U26} (62256), \refdes{D6} (1N4148), \refdes{C10} and \refdes{C11} (\pF{33}), \refdes{X3} (\MHz{10.738635}), \refdes{R19} (\SI{470}{\ohm}), \refdes{R20} and \refdes{R21} (\SI{75}{\ohm}), \refdes{C12} (\uF{22}), \refdes{C13} (\uF{0.1}), \refdes{C15} (\uF{220}), \refdes{L1} (ferrite bead), \refdes{Q1} (2N3904), and \refdes{J6}. Also install decoupling capacitors.
\end{itemize}

\end{document}

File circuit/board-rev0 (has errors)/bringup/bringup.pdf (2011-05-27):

## Ultim809 Rev 0 Board Bringup Procedure

Matt Sarnoff

May 11, 2011

## 1 Board Errors

### 1.1 U4 TSC

Pin 39 of U4 (TSC) is incorrectly connected to Vcc. It should be connected to GND. Cut the trace on the top side of the board as follows:

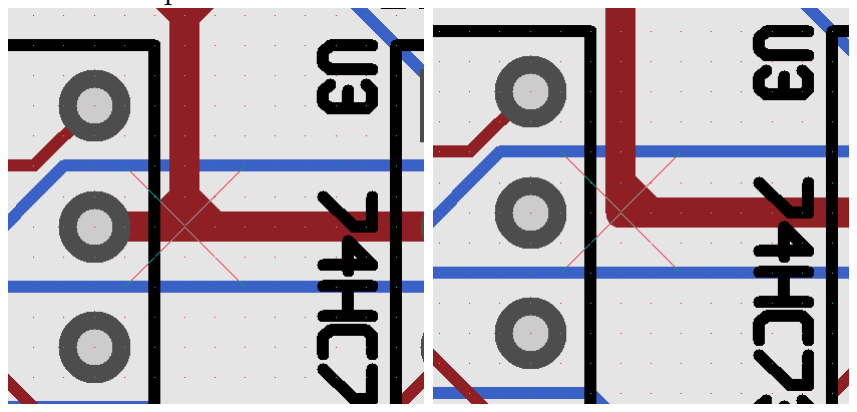
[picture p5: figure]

On the bottom of the board, solder a piece of enameled magnet wire or wire-wrap wire from pin 39 to pin 1.

### 1.2 U16 TX and RX swapped

U16 pin 10 (RX) is mistakenly connected to J2 pin 5 (RXD), and U16 pin 11 (TX) is mistakenly connected to J2 pin 4 (TXD). These two need to be swapped. Since it is difficult to fix this on the board, you will have to fashion an adapter on a piece of perfboard.

### 1.3 CSW and CSR swapped

U21 pin 14 (CSW) is mistakenly connected to U17 pin 11 and U21 pin 15 (CSR) is mistakenly connected to U17 pin 10. The two should be swapped. Cut traces on the back of the board at U17 pin 10-11. Add a wire from U17 pin 11 to U21 pin 15 and a wire from U17 pin 10 to U21 pin 14.

### 1.4 VRAM bus incorrect

Cut the traces on the back of the board at U23 pin 12 and U26 pin 26. Add a wire from U23 pin 19 to U26 pin 4 and a wire from U24 pin 19 to U26 pin 26.

1

## 2 Assembly and testing

### 2.1 Sockets

- Install all IC sockets.

### 2.2 Power

- Install D2 (power LED), R3 (1 kΩ), D1 (1N4001), C2 and C4 (0.1 µF), C1 and C3 (10 µF electrolytic, rated for 50 V), U1 (7805), J1, and S1.
- Ensure S1 is in the down (disconnected) position.
- Connect 9 V DC power to J1. The center pin is positive and the outer ring is ground.
- Turn on S1. D2 should light.
- Measure Vcc (for example, at U14 pin 16) and ensure it is roughly 5 V.

### 2.3 Clock signals

- Install X1 (8 MHz), U3 (74HC73), and decoupling capacitor C16.
- Turn on power.
- Using a frequency counter, measure the clock signals. U3 pin 1 should read 8 MHz. U4 pin 34 (E) and U4 pin 35 (Q) should read 2 MHz.
- Using a two-channel oscilloscope or logic analyzer, observe the E (U4 pin 34) and Q (U4 pin 35) waveforms.

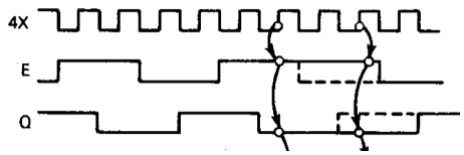
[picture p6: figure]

### 2.4 Processor integrity

- Install RN1 (10 kΩ), C6 (10 µF), D3 and D4, R4 and R5 (1 kΩ), S5, S2, and S3.
- Flip S5 up to HALT.
- Turn on power.
- Ensure U4 pin 40 (HALT) is 0 V.
- Ensure pin U4 (37)RESET, pin 2 (NMI), pin 3 (IRQ), and pin 4 (FIRQ) are 5 V.

2

- Flip S5 down to RUN and ensure pin 40 is 5 V.
- Ensure pin 37 is 0 V when S2 is depressed and pin 2 is 0 V when S3 is depressed.
- Turn off power, install U4 (68B09E) and decoupling capacitor C17.
- Flip S5 up to HALT and turn on power.
- Ensure D3 and D4 are both lit. This indicates the processor is in good condition.

### 2.5 ROM, program execution, and address decoding

- Burn romtest1.s19 to an 8K×8 EEPROM, using the Arduino ROMBurner and the ser09 utility.
- Install the EEPROM in U9, and install U5 (74HC00), U7 (74HC139), RN3 (10 kΩ), S4, and associated decoupling capacitors.
- Flip S4 to the left (EEPROM WRITE PROTECT ON) and ensure U9 pin 27 (WE) is connected to RN3 pin 6. (Resistance between pin 27 and Vcc is 10 kΩ.)
- Flip S4 to the right (EEPROM WRITE PROTECT OFF) and ensure pin 27 is connected to U8 pin 29 (WR).
- Flip S4 to the left and flip S5 to HALT.
- Turn on power. D3 and D4 should light.
- Flip S5 to RUN. D3 and D4 should turn off. The program should now be running. After about one second, D3 should light (SYNC acknowledge), indicating the test program is finished. Pressing S2 or S3 will restart the program: the light will go out, and should come on about a second later.
- Turn off power.
- With a logic analyzer, attach probes to U4 pins 8-23 (A0-A15), U4 pin 34 (E), U4 pin 32 (R/W), U5 pin 6 (RAMSEL), U7 pin 4 (IOSEL), U7 pin 5 (ROMSEL), U7 pin 9 (RD), and U7 pin 10 (WR). The positive edge of E should be used as the clock signal.
- Set S5 to HALT, run the logic analyzer, and set S5 to RUN. Repeat multiple times to verify the following truth table:

3

E | R/W | RD | WR
0 | x | 1 | 1
1 | 1 | 0 | 1
1 | 0 | 1 | 0
A0-A15 | RAMSEL | IOSEL | ROMSEL
$0xxx | 0 | 1 | 1
$1xxx | 0 | 1 | 1
$2xxx | 0 | 1 | 1
$3xxx | 0 | 1 | 1
$4xxx | 0 | 1 | 1
$5xxx | 0 | 1 | 1
$6xxx | 0 | 1 | 1
$7xxx | 0 | 1 | 1
$8xxx | 0 | 1 | 1
$9xxx | 0 | 1 | 1
$Axxx | 0 | 1 | 1
$Bxxx | 0 | 1 | 1
$Cxxx $Dxxx | 1 1 | 0 0 | 1 1
$Exxx $Fxxx | 1 1 | 1 1 | 0 0

The test program attempts to read and write to successive addresses, so the address decoding may be observed.

### 2.6 I/O decoding

- Install U6 (74HC14), U10 (74HC138), and associated decoupling capacitors.
- Attach logic analyzer probes to U4 pins 8-23 (A0-A15), U10 pin 15 (VIASEL), U10 pin 14 (UARTSEL), U10 pin 13 (SRSEL), U10 pin 12 (AVSEL), U10 pin 11 (EXT1SEL), U10 pin 10 (EXT2SEL), U10 pin 9 (EXT3SEL), U10 pin 7 (EXT4SEL), and U5 pin 8 (EXTIOSEL). The positive edge of E should be used as the clock signal.
- Run romtest1.s19 again and verify the following truth table:
A0-A15 | VIA | UART | SR | AV | EXT1 | EXT2 | EXT3 | EXT4 | EXTIO
$Bxxx $C000-$C3FF $C400-$C7FF $C800-$CBFF $CC00-$CFFF $D000-$D3FF $D400-$D7FF $D800-$DBFF $DC00-$DFFF $Exxx | 1 0 1 1 1 1 1 1 1 1 | 1 1 0 1 1 1 1 1 1 1 | 1 1 1 0 1 1 1 1 1 1 | 1 1 1 1 0 1 1 1 1 1 | 1 1 1 1 1 0 1 1 1 1 | 1 1 1 1 1 1 0 1 1 1 | 1 1 1 1 1 1 1 0 1 1 | 1 1 1 1 1 1 1 1 0 1 | 1 1 1 1 1 0 0 0 0 1

4

### 2.7 UART

- Install U16 (16C550), decoupling capacitor C29, R10 (1 MΩ), R11 (1.5 kΩ), C8 (27 pF), C9 (47 pF), X2 (1.8432 MHz), J2, R1 (330 Ω), R2 (1.5 kΩ), and D5. Orient D5 so the shortest lead (the green anode) is on the left and is inserted into the square hole.
- Burn romtest2.s19 onto the EEPROM.
- Connect a 5 V FTDI USB-to-serial cable to J2, with the black wire on the right. Connect the other end to a PC. Start a terminal program listening at 38400 baud, 8 data bits, no parity, 1 stop bit.
- Turn on the system and run the program.
- The status LED D5 should turn off and the system should print the following:

Hello World!
Type r, y, g, or o to change LED color

Typing one of the four letters from the terminal changes the LED color (red, yellow, green, off) and prints a message. (“Red.” or “Yellow.” or “Green.” or “Off.”)

- Additionally, use a frequency counter to check the UART’s clock rate at U16 pin 9. It should be 16× the baud rate: in this case, approximately 614 400 Hz.

### 2.8 RAM and bank switching

- Install diode D7 (1N4148).
- Test D7 using a multimeter in diode mode. Place the positive lead on U4 pin 4 (FIRQ) and place the negative lead on U11 pin 21 (IRQ). (U11 should not be installed yet.) The meter should read a small positive voltage. Reverse the leads and the meter should indicate an open circuit.
- Install U8 (512K SRAM), U11 (W65C22S), U12 (74HC157), U13 (74HC08), and associated decoupling capacitors.
- Burn romtest3.s19 onto the EEPROM.
- Connect the serial cable and start the terminal as in the previous step.
- Run the program. It tries to determine the size of the RAM by cycling through the 16K pages and counting them until it detects wraparound. It should print

0512KB RAM available.

on the console.

5

### 2.9 Audio/video I/O decoding

- Install U17 (74HC139), U18 (74HC02), U19 (74HC74), and associated decoupling capacitors.
- Burn romtest4.s19 onto the EEPROM.
- Attach logic analyzer probes to U17 pin 1 (AVSEL), U17 pin 2-3 (A1-A2), U17 pin 4 (VDPSEL), U17 pin 5 (PSGSEL), U17 pin 6 (FF1SEL), U17 pin 7 (FF2SEL), U17 pin 13 (RD), U17 pin 14 (WR), U17 pin 10 (CSR), U17 pin 11 (CSW), U18 pin 3 (A0), U18 pin 1 (BC1), U18 pin 4 (BDIR), U18 pin 13 (FF1CP), U18 pin 10 (FF2CP), U19 pin 3 (A3), U19 pin 5 (VBANK), and U19 pin 9 (PADSELECT). The positive edge of E should be used as the clock signal.
- Run the program and verify the following truth tables:
AVSEL | A0-A2 | RD | WR | VDPSEL | PSGSEL | FF1SEL | FF2SEL | CSR | CSW
1 0 0 0 0 0 | %xxx %00x %00x %01x %10x %11x | x 1 0 x x x | x 0 1 x x x | 1 0 0 1 1 1 | 1 1 1 0 1 1 | 1 1 1 1 0 1 | 1 1 1 1 1 0 | 1 1 0 1 1 1 | 1 0 1 1 1 1
AVSEL | PSGSEL | A0-A2 | RD | WR | BC1 | BDIR
1 0 0 0 0 | 1 0 0 0 0 | %xxx %010 %010 %011 %011 | x x x x x | x 0 1 0 1 | 0 1 1 0 0 | 0 1 0 1 0
AVSEL | FF1SEL | FF2SEL | RD | A3 | FF1CP | FF2CP | VBANK | PADSELECT
1 0 0 0 0 0 | 1 0 0 0 1 1 | 1 1 1 1 0 0 | x 1 0 0 0 0 | x x 0 1 0 1 | 0 0 1 1 0 0 | 0 0 0 0 1 1 | no change no change 0 1 no change no change | no change no change no change no change 0 1

### 2.10 Audio/gamepads

- Install U20 (YM2149), R6, R7, and R8 (1 kΩ), R9 (4.7 kΩ), C7 (1 µF), J9, and J10. Also install decoupling capacitors.

### 2.11 Video

- Install U21 (TMS9918A), U22 (74HC04), U23, U24, and U25 (74HC574), U26 (62256), D6 (1N4148), C10 and C11 (33 pF), X3 (10.738 635 MHz), R19 (470 Ω), R20 and R21 (75 Ω), C12 (22 µF), C13 (0.1 µF), C15 (220 µF), L1 (ferrite bead), Q1 (2N3904), and J6. Also install decoupling capacitors.

6

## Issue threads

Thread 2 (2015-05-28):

error in schematic

phiber1, 2015-05-28:
Hello Matt, I happened to notice an error in your schematic.  Specifically U17, the second decoder in the 74139 being used to do the chip-select read and chip-select write on the VDP... Your decoding of A and B to Y1 and Y2 is backwards.  If you consult the truth table, \A -> \Y2, and \B -> \Y1.  So you either need to reverse your schematic wiring of \WR and \RD at the inputs, or otherwise reverse \CSW and \CSR at the outputs.  Either or.  Otherwise the VDP obviously won't work at all.

Regards,
Mark

74hc595, 2018-09-21:
This is a known error and is documented here: https://github.com/74hc595/Ultim809/blob/master/circuit/board-rev0%20(has%20errors)/rev0-errors.txt

Sorry it has taken an eternity for me to respond! This project has been on the shelf for a while. I'd love to do a second revision of the Ultim809 and fix the errors one of these days.

phiber1, 2018-09-21:
So it is! I've never actually built your system, but I created my own 63C09
homebrew some years back which runs FLEX and CUBIX OSes.
I have a different sound chip in mine, but I did adapt your Asteroids game
to run on my system, adjusting for the sounds. I also corrected the "OUT OF
OBJECTS!" error for those of us that actually play well and go on for a
while.  :)
Well done.

-Mark

On Fri, Sep 21, 2018 at 12:12 PM, Matt Sarnoff <notifications@github.com>
wrote:

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

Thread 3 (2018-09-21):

name of the library book used for your design?

xedover, 2018-09-21:
You said you "found a microcomputer design book at the library that uses the 6809 in its examples." Can you tell us the name of the book?

cbmeeks, 2018-09-21:
+1

74hc595, 2018-09-21:
Oh boy. I can't remember the name, but it was already out of print when I checked it out. I recall it was the first edition of the book; later editions used the 68000. It wasn't a large book; maybe half an inch thick.

I think my only lead might be to find my old Santa Clara County Library card, log into their website, and  see if it's in my checkout history.

phiber1, 2018-09-21:
Now that I have your attention, there's a crucial error in your schematic
in the graphics logic section. I opened an issue about it a few years ago.

-Mark

On Fri, Sep 21, 2018, 11:56 AM Matt Sarnoff <notifications@github.com>
wrote:

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

74hc595, 2018-09-21:
@phiber1 Thank you for the reminder, I just replied to your issue.

74hc595, 2018-09-22:
*This is it!* _Microprocessor System Design Fundamentals_ by Kenneth J. Breeding: https://www.amazon.com/Microprocessor-System-Fundamentals-Kenneth-Breeding/dp/0135642795

Closed 2018-09-22.

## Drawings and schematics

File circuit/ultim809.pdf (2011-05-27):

## 40VDD

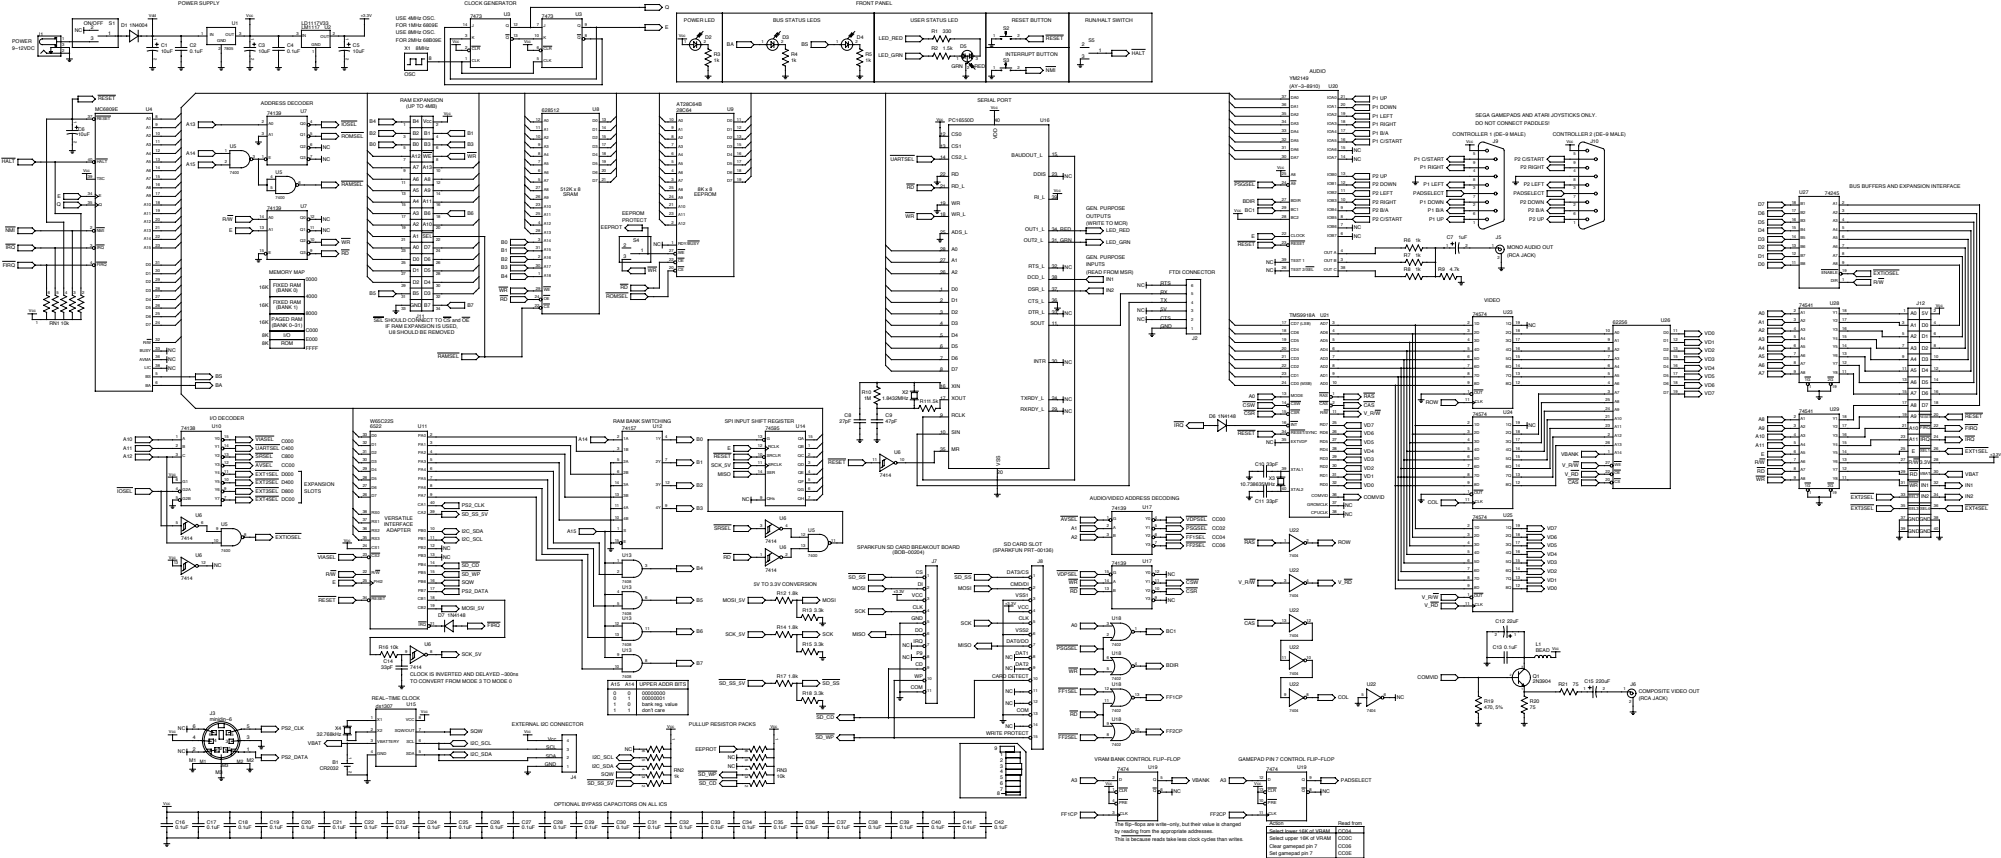
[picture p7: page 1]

SEGA GAMEPADS AND ATARI JOYSTICKS ONLY.
DO NOT CONNECT PADDLES!

BUS BUFFERS AND EXPANSION INTERFACE

SEL SHOULD CONNECT TO CS and OE
IF RAM EXPANSION IS USED,
U8 SHOULD BE REMOVED

SPI INPUT SHIFT REGISTER

AUDIO/VIDEO ADDRESS DECODING

GNDGND

GND | GND

SPARKFUN SD CARD BREAKOUT BOARD

CLOCK IS INVERTED AND DELAYED ~300ns
TO CONVERT FROM MODE 3 TO MODE 0

A15 A14 | UPPER ADDR BITS
0 0 0 1 1 0 1 1 | 00000000 00000001 bank reg. value don’t care

VRAM BANK CONTROL FLIPïFLOP

GAMEPAD PIN 7 CONTROL FLIPïFLOP

The flipïflops are writeïonly, but their value is changed
by reading from the appropriate addresses.
This is because reads take less clock cycles than writes.

Select lower 16K of VRAM | CC04
Select upper 16K of VRAM Clear gamepad pin 7 Set gamepad pin 7 | CC0C CC06 CC0E

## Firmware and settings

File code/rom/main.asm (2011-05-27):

; vim:noet:sw=8:ts=8:ai:syn=as6809
; Matt Sarnoff (msarnoff.org/6809) - May 26, 2010

	.area	_CODE(ABS)

	.nlist
	.include "6809.inc"
	.list

;************ Customizable vectors in zero page ************
	.org	SYSRAM
SWI3VEC:	.rmb	2		;SWI3 vector
SWI2VEC:	.rmb	2		;SWI2 vector
FIRQVEC:	.rmb	2		;FIRQ vector
IRQVEC:		.rmb	2		;IRQ vector
SWIVEC:		.rmb	2		;SWI vector
NMIVEC:		.rmb	2		;NMI vector
OUTCH:		.rmb	2		;pointer to character output function
INCH:		.rmb	2		;pointer to character input function

;************ Zero page system variables ************
NUMRAMPAGES:	.rmb	1		;number of 16K pages
RAM_KB_BCD:	.rmb	2		;RAM size in BCD kilobytes
L:		.rmb	4
LH		.equ	L
LL		.equ	L+2
CURSORPOS:	.rmb	2
KEYSTATE:	.rmb	1
KBD_SAVE:	.rmb	1
KBD_BITSLEFT:	.rmb	1
KBD_SCANCODE:	.rmb	1

	.org	(SYSRAM-2)+0x20
KBD_BUFSTART:	.rmb	16
KBD_BUFEND	.equ	.-1
KBD_BUFMASK	.equ	0b11101111

KBD_HEADPTR:	.rmb	1
KBD_HEADPTR_L:	.rmb	1
KBD_TAILPTR:	.rmb	1
KBD_TAILPTR_L:	.rmb	1


;COUNT:		.rmb	2		;16-bit temporary

;************ Main routine ************
	.org	ROMSTART
MAIN:		lds	#ROMSTKSTART+1	;set up ROM stack pointer
		lda	#ROMDP		;set up direct page register
		tfr	a,dp

; set up VIA and memory banking, calculate RAM size
		lda	#0xFF		;port A (page register) all outputs
		sta	VIA_DDRA
		bsr	CALCRAMSIZE
		lda	#2		;bank in ram page 2
		sta	PAGE

; set up serial port
		ldx	#B38400		;set UART to 38400 baud
		bsr	UART_INIT	;initialize UART

; set up I/O functions
		bsr	UART_IO

; load the interrupt vectors
		ldd	#STARTUP	;SWI2 returns to startup screen
		std	*SWI2VEC
		ldd	#DUMMY_VECTOR
		std	*SWI3VEC	;SWI3 does nothing
		std	*IRQVEC		;IRQ does nothing
		std	*FIRQVEC	;FIRQ does nothing
		std	*SWIVEC

		ldd	#REMOTEMONITOR
		std	*NMIVEC

; start
		;jmp	STARTUP
		jmp	0x0100
		;swi2			;show the startup screen

; should not get here! loop forever
done:		bra	.		;wait

;************ Include files ************

		.include "memcheck.asm"
		.include "uart.asm"
		.include "output.asm"
		.include "tms9918.asm"
		.include "kbd6522.asm"
		.include "keydecode.asm"
		.include "console.asm"
		.include "startup.asm"
		.include "remote.asm"
		;.include "monitor.asm"

;************ Strings ************
	.org 0xFF8B
ultim809:	.asciz	"ULTIM809"
version:	.asciz	"ROM v0.6, 10 May 2011"
ramavail:	.asciz	"KB RAM available"
monitorinst:	.asciz	"Press INTERRUPT for monitor"

;************ Interrupt handlers ************
SWI3_HANDLER:	jmp	[SWI3VEC]
SWI2_HANDLER:	jmp	[SWI2VEC]
FIRQ_HANDLER:	jmp	[FIRQVEC]
IRQ_HANDLER:	jmp	[IRQVEC]
SWI_HANDLER:	jmp	[SWIVEC]
NMI_HANDLER:	jmp	[NMIVEC]

; dummy interrupt handler does nothing
DUMMY_VECTOR::	rti

;************ Interrupt vectors **********
	.org 0xFFF0
		.fdb	0x0000	;reserved
	.org 0xFFF2
		.fdb	SWI3_HANDLER
	.org 0xFFF4
		.fdb	SWI2_HANDLER
	.org 0xFFF6
		.fdb	FIRQ_HANDLER
	.org 0xFFF8
		.fdb	IRQ_HANDLER
	.org 0xFFFA
		.fdb	SWI_HANDLER
	.org 0xFFFC
		.fdb	NMI_HANDLER
	.org 0xFFFE
RESET:		.fdb	MAIN

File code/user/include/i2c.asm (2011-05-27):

; vim:noet:sw=8:ts=8:ai:syn=as6809
; Matt Sarnoff (msarnoff.org/6809) - September 15, 2010
;
;************ I2C bit-banging routines ************
;Uses the 6522 Versatile Interface Adapter in the following configuration:
;Port B pin 0: SDA
;Port B pin 1: SCL
;All other port B pins should be inputs or unused
;
;I2C is open-drain, so:
; - logic high is output by leaving the line pulled up to Vcc (DDR bit = 0)
; - logic low is output by pulling the line to ground (DDR bit = 1)
;
;Port B output register is always all zeros.


;************ Definitions ************

SDA		.equ	0b01
SCL		.equ	0b10

;;; initializes the I2C system
;;; arguments:	none
;;; returns:	none
;;; destroys:	A
I2C_INIT::	clr	VIA_DDRB	;all pins inputs
		clr	VIA_ORB		;all pins low when in output mode
		rts


;;; send start condition (pull SDA low while SCL stays high)
;;; SCL and SDA must already be high
;;; arguments:	none
;;; returns:	none
;;; destroys:	A
I2C_START::	lda	#SDA		;SDA becomes an output (pulled low)
		sta	VIA_DDRB
		rts			;now SCL is high and SDA is low


;;; send stop condition (pull SDA high while SCL stays high)
;;; SCL and SDA must be low
;;; arguments:	none
;;; returns:	none
;;; destroys:	A
I2C_STOP::	lda	#SDA|(~SCL)	;bring SCL high, leaving SDA low
		sta	VIA_DDRB	;now SCL is high
		clr	VIA_DDRB	;now bring SDA high
		rts


;;; send a byte
;;; SCL must be high, SDA must be low (start condition already sent)
;;; arguments:	byte in B
;;; returns:	none
;;; destroys:	A
I2C_WRITE::	pshs	dp,cc
		orcc	#0b01010000	;disable interrupts
		lda	#VIA_PAGE	;so nothing messes up DP
		tfr	a,dp
		comb			;SDA output is inverted
		lda	#SCL|SDA	;will set SCL low, keeping SDA low
; send bit 7
		lslb			;get MSB out of A, into carry flag
		sta	*VIA_DDRB_D	;set SCL and SDA low (C not affected)
		anda	#~SDA		;get data bit ready (C not affected)
		adca	#0		;set data bit from carry flag
		sta	*VIA_DDRB_D	;set data bit
		anda	#~SCL		;will bring SCL high
		sta	*VIA_DDRB_D	;SCL rising edge (slave reads data bit)
		ora	#SCL		;will bring SCL low
		nop			;wait a little for slave to read bit
; send bit 6
		lslb
		sta	*VIA_DDRB_D	;SCL falling edge
		anda	#~SDA
		adca	#0
		sta	*VIA_DDRB_D	;SDA set
		anda	#~SCL
		sta	*VIA_DDRB_D	;SCL rising edge
		ora	#SCL
		nop
; send bit 5
		lslb
		sta	*VIA_DDRB_D	;SCL falling edge
		anda	#~SDA
		adca	#0
		sta	*VIA_DDRB_D	;SDA set
		anda	#~SCL
		sta	*VIA_DDRB_D	;SCL rising edge
		ora	#SCL
		nop
; send bit 4
		lslb
		sta	*VIA_DDRB_D	;SCL falling edge
		anda	#~SDA
		adca	#0
		sta	*VIA_DDRB_D	;SDA set
		anda	#~SCL
		sta	*VIA_DDRB_D	;SCL rising edge
		ora	#SCL
		nop
; send bit 3
		lslb
		sta	*VIA_DDRB_D	;SCL falling edge
		anda	#~SDA
		adca	#0
		sta	*VIA_DDRB_D	;SDA set
		anda	#~SCL
		sta	*VIA_DDRB_D	;SCL rising edge
		ora	#SCL
		nop
; send bit 2
		lslb
		sta	*VIA_DDRB_D	;SCL falling edge
		anda	#~SDA
		adca	#0
		sta	*VIA_DDRB_D	;SDA set
		anda	#~SCL
		sta	*VIA_DDRB_D	;SCL rising edge
		ora	#SCL
		nop
; send bit 1
		lslb
		sta	*VIA_DDRB_D	;SCL falling edge
		anda	#~SDA
		adca	#0
		sta	*VIA_DDRB_D	;SDA set
		anda	#~SCL
		sta	*VIA_DDRB_D	;SCL rising edge
		ora	#SCL
		nop
; send bit 0
		lslb
		sta	*VIA_DDRB_D	;SCL falling edge
		anda	#~SDA
		adca	#0
		sta	*VIA_DDRB_D	;SDA set
		anda	#~SCL
		sta	*VIA_DDRB_D	;SCL rising edge
		ora	#SCL
		nop
		nop
		sta	*VIA_DDRB_D	;SCL falling edge
; release SDA so slave can send ACK bit
		anda	#~SDA		;bring SDA high
		sta	*VIA_DDRB_D
		anda	#~SCL
		sta	*VIA_DDRB_D	;SCL rising edge
		nop
		nop
		ora	#SCL
		sta	*VIA_DDRB_D	;SCL falling edge
; bring SDA low
		ora	#SDA
		sta	*VIA_DDRB_D
; SCL and SDA are now both low, stop condition may be sent
		puls	dp,cc,pc


;;; receive a byte, send ACK to the slave
;;; arguments:	none
;;; returns:	byte in B
;;; destroys:	A
I2C_READ_ACK::	pshs	dp,cc
		orcc	#0b01010000	;disable interrupts
		lda	#VIA_PAGE	;so nothing messes up DP
		tfr	a,dp
		bsr	I2C_READ	;read byte
; SCL is low and SDA is high, pull SDA low to send ACK
		lda	#SCL|SDA
		sta	*VIA_DDRB_D	;pull SDA low
		anda	#~SCL
		sta	*VIA_DDRB_D	;SCL rising edge
		nop
		nop
		ora	#SCL
		sta	*VIA_DDRB_D	;SCL falling edge
; SCL and SDA are now low
		puls	dp,cc,pc


;;; receive a byte, send NACK to the slave
;;; arguments:	none
;;; returns:	byte in B
;;; destroys:	A
I2C_READ_NACK::	pshs	dp,cc
		orcc	#0b01010000	;disable interrupts
		lda	#VIA_PAGE	;so nothing messes up DP
		tfr	a,dp
		bsr	I2C_READ	;read byte

; SCL is low, leave SDA high to send NACK
		clra
		sta	*VIA_DDRB_D	;SCL rising edge
		nop
		nop
		ora	#SCL
		sta	*VIA_DDRB_D	;SCL falling edge
		ora	#SDA
		sta	*VIA_DDRB_D	;pull SDA low, to prepare for stop
; SCL and SDA are now low
		puls	dp,cc,pc


;;; receive a byte, without sending ACK or NACK
;;; direct page register must be properly set to VIA_PAGE
;;; arguments:	none
;;; returns:	byte in B
;;; destroys:	A
I2C_READ:	clrb
; pull SCL low (prepare for first clock)
		lda	*VIA_DDRB_D
		ora	#SCL
		sta	*VIA_DDRB_D	;SCL falling edge
; SDA is still an input, but SCL is now an output
; release SDA so slave can set data bit
		anda	#~SDA
		sta	*VIA_DDRB_D	;SDA released

; clock in bit 7
		clr	*VIA_DDRB_D	;SCL rising edge
		lda	*VIA_IRB_D	;read data line
		lsra			;shift data into carry bit
		lda	#SCL
		sta	*VIA_DDRB_D	;SCL falling edge
		rolb			;shift carry bit into result
		nop
; clock in bit 6
		clr	*VIA_DDRB_D	;SCL rising edge
		lda	*VIA_IRB_D
		lsra
		lda	#SCL
		sta	*VIA_DDRB_D	;SCL falling edge
		rolb
		nop
; clock in bit 5
		clr	*VIA_DDRB_D	;SCL rising edge
		lda	*VIA_IRB_D
		lsra
		lda	#SCL
		sta	*VIA_DDRB_D	;SCL falling edge
		rolb
		nop
; clock in bit 4
		clr	*VIA_DDRB_D	;SCL rising edge
		lda	*VIA_IRB_D
		lsra
		lda	#SCL
		sta	*VIA_DDRB_D	;SCL falling edge
		rolb
		nop
; clock in bit 3
		clr	*VIA_DDRB_D	;SCL rising edge
		lda	*VIA_IRB_D
		lsra
		lda	#SCL
		sta	*VIA_DDRB_D	;SCL falling edge
		rolb
		nop
; clock in bit 2
		clr	*VIA_DDRB_D	;SCL rising edge
		lda	*VIA_IRB_D
		lsra
		lda	#SCL
		sta	*VIA_DDRB_D	;SCL falling edge
		rolb
		nop
; clock in bit 1
		clr	*VIA_DDRB_D	;SCL rising edge
		lda	*VIA_IRB_D
		lsra
		lda	#SCL
		sta	*VIA_DDRB_D	;SCL falling edge
		rolb
		nop
; clock in bit 0
		clr	*VIA_DDRB_D	;SCL rising edge
		lda	*VIA_IRB_D
		lsra
		lda	#SCL
		sta	*VIA_DDRB_D	;SCL falling edge
		rolb
		rts
